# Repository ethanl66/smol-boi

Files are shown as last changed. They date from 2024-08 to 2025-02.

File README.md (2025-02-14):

# Smol boi

Custom 40% Keyboard PCB design files designed with KiCad 5.1.4. 
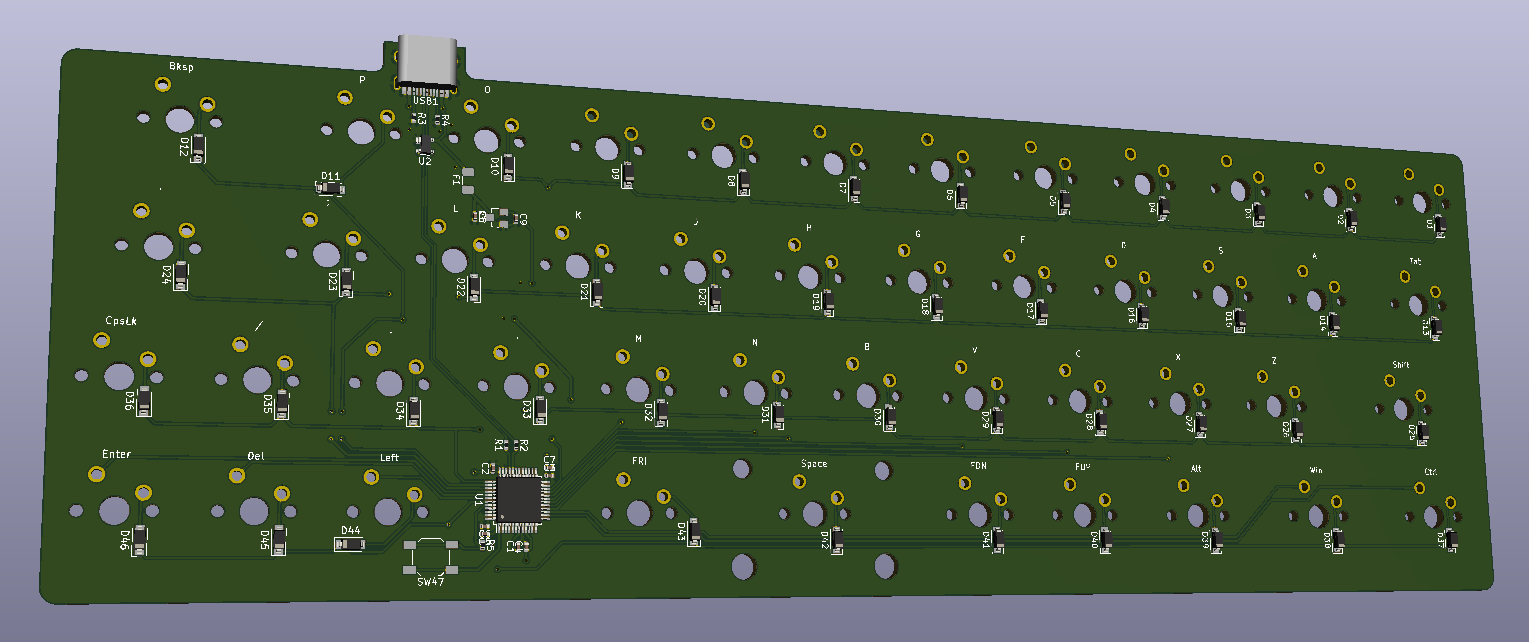
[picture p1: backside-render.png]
Backside Render of PCB Containing MCU and circuit elements Backside Render

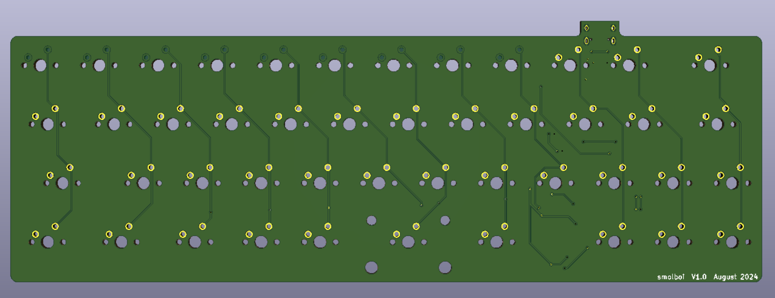
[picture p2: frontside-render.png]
Front Render of PCB Containing circuit elements Frontside Render


## Description

Smol Boi is a custom personal 40% keyboard PCB designed to provide a compact and efficient layout. This repository contains the KiCad design files including schematic and layout.
Firmware can be found at https://github.com/ethanl66/smolboi-firmware-v1.0

## Features

- 40% layout
- Custom layout with 46 keys
- USB-C connnectivity
- Flashable with DFU mode using USB-C
- Planned features for V2.0: LED indicators, hot-swap sockets, Bluetooth/2.4 GHz dongle, daughterboard, knob

## Contents

- `smolboi-pcb.sch`: Contains the PCB schematic
- `smolboi-pcb.kicad_pcb`: Contains the routing layout

## Acknowledgments

- Inspired by the community of keyboard enthusiasts
- Would not have been possible without r/MechanicalKeyboards

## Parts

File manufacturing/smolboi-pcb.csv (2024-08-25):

Comment | Designator | Footprint | LCSC
0.1uF | C1,C2,C3,C4,C5,C6 | Capacitor_SMD:C_0402_1005Metric | C307331
4.7uF | C7 | Capacitor_SMD:C_0402_1005Metric | C23733
1uF | C8,C9 | Capacitor_SMD:C_0402_1005Metric | C52923
D | D1,D2,D3,D4,D5,D6,D7,D8,D9,D10,D11,D12,D13,D14,D15,D16,D17,D18,D19,D20,D21,D22,D23,D24,D25,D26,D27,D28,D29,D30,D31,D32,D33,D34,D35,D36,D37,D38,D39,D40,D41,D42,D43,D44,D45,D46 | Diode_SMD:D_SOD-123 | C77978
500mA | F1 | Fuse:Fuse_1206_3216Metric | C70069
22 | R1,R2 | Resistor_SMD:R_0402_1005Metric | C6117666
5.1k | R3,R4 | Resistor_SMD:R_0402_1005Metric | C400635
10k | R5 | Resistor_SMD:R_0402_1005Metric | C850723
ESC | SW1 | MX_Only:MXOnly-1U-NoLED
O | SW10 | MX_Only:MXOnly-1U-NoLED
P | SW11 | MX_Only:MXOnly-1U-NoLED
Bksp | SW12 | MX_Only:MXOnly-1.75U-NoLED
Tab | SW13 | MX_Only:MXOnly-1.25U-NoLED
A | SW14 | MX_Only:MXOnly-1U-NoLED
S | SW15 | MX_Only:MXOnly-1U-NoLED
D | SW16 | MX_Only:MXOnly-1U-NoLED
F | SW17 | MX_Only:MXOnly-1U-NoLED
G | SW18 | MX_Only:MXOnly-1U-NoLED
H | SW19 | MX_Only:MXOnly-1U-NoLED
Q | SW2 | MX_Only:MXOnly-1U-NoLED
J | SW20 | MX_Only:MXOnly-1U-NoLED
K | SW21 | MX_Only:MXOnly-1U-NoLED
L | SW22 | MX_Only:MXOnly-1U-NoLED
; | SW23 | MX_Only:MXOnly-1U-NoLED
' | SW24 | MX_Only:MXOnly-1.5U-NoLED
Shift | SW25 | MX_Only:MXOnly-1.75U-NoLED
Z | SW26 | MX_Only:MXOnly-1U-NoLED
X | SW27 | MX_Only:MXOnly-1U-NoLED
C | SW28 | MX_Only:MXOnly-1U-NoLED
V | SW29 | MX_Only:MXOnly-1U-NoLED
W | SW3 | MX_Only:MXOnly-1U-NoLED
B | SW30 | MX_Only:MXOnly-1U-NoLED
N | SW31 | MX_Only:MXOnly-1U-NoLED
M | SW32 | MX_Only:MXOnly-1U-NoLED
, | SW33 | MX_Only:MXOnly-1U-NoLED
. | SW34 | MX_Only:MXOnly-1U-NoLED
/ | SW35 | MX_Only:MXOnly-1U-NoLED
CpsLk | SW36 | MX_Only:MXOnly-1U-NoLED
Ctrl | SW37 | MX_Only:MXOnly-1.25U-NoLED
Win | SW38 | MX_Only:MXOnly-1.25U-NoLED
Alt | SW39 | MX_Only:MXOnly-1.25U-NoLED
E | SW4 | MX_Only:MXOnly-1U-NoLED
FUP | SW40 | MX_Only:MXOnly-1U-NoLED
FDN | SW41 | MX_Only:MXOnly-1U-NoLED
Space | SW42 | MX_Only:MXOnly-2U-NoLED
FRI | SW43 | MX_Only:MXOnly-1U-NoLED
Left | SW44 | MX_Only:MXOnly-1U-NoLED
Del | SW45 | MX_Only:MXOnly-1U-NoLED
Enter | SW46 | MX_Only:MXOnly-1U-NoLED
SW_Push | SW47 | Button_Switch_SMD:SW_SPST_SKQG_WithStem | C115351
R | SW5 | MX_Only:MXOnly-1U-NoLED
T | SW6 | MX_Only:MXOnly-1U-NoLED
Y | SW7 | MX_Only:MXOnly-1U-NoLED
U | SW8 | MX_Only:MXOnly-1U-NoLED
I | SW9 | MX_Only:MXOnly-1U-NoLED
STM32F072CBTx | U1 | Package_QFP:LQFP-48_7x7mm_P0.5mm | C81720
PRTR5V0U2X | U2 | random-keyboard-parts:SOT143B | C12333
XC6206 | U3 | PMIC-LDO-XC6206P332MR-G_SOT23_:SOT-23 | C5446
HRO-TYPE-C-31-M-12 | USB1 | Type-C:HRO-TYPE-C-31-M-12-Assembly | C165948

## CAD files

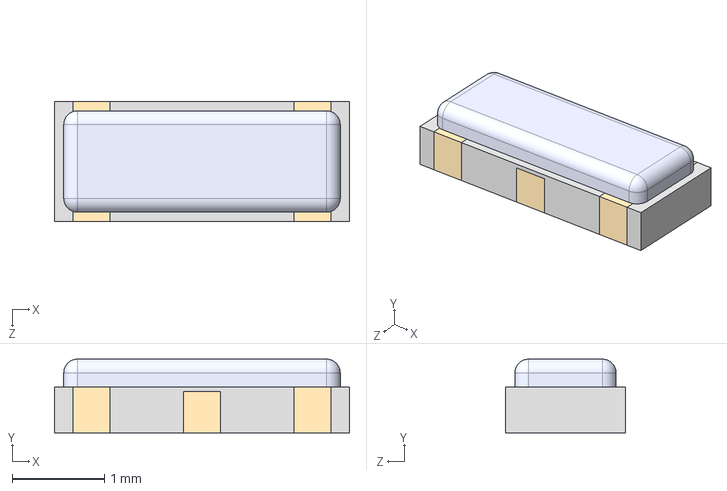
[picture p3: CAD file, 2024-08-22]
CSTNE8M00GH5C000R0/CSTNE8M00GH5C000R0.step
3.20 x 0.8 x 1.30 mm

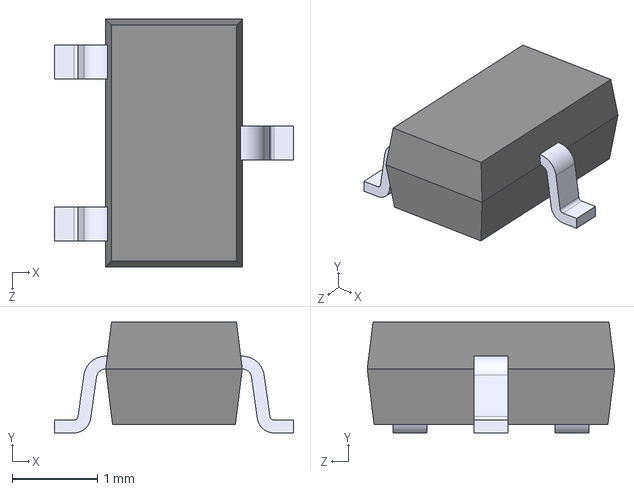
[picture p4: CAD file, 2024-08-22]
PMIC-LDO-XC6206P332MR-G_SOT23_/PMIC-LDO-XC6206P332MR-G_SOT23_.step
2.80 x 1.30 x 2.90 mm

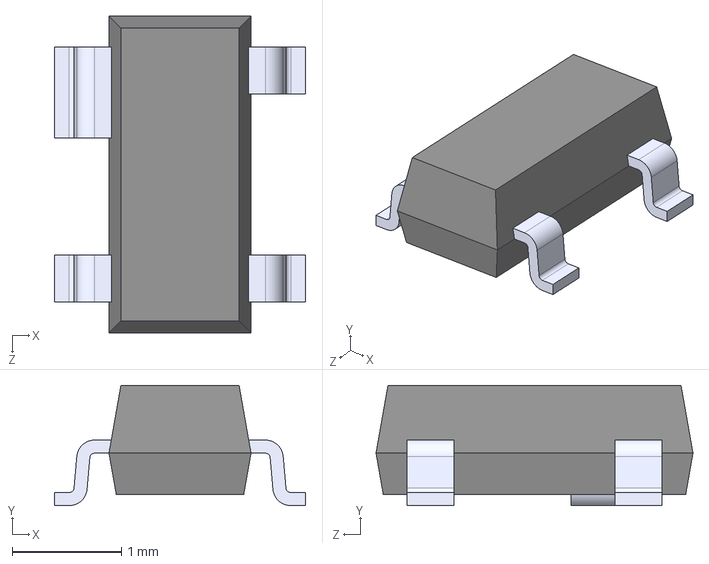
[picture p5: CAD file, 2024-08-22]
PRTR5V0U2X_215/PRTR5V0U2X_215.step
2.30 x 1.10 x 2.90 mm

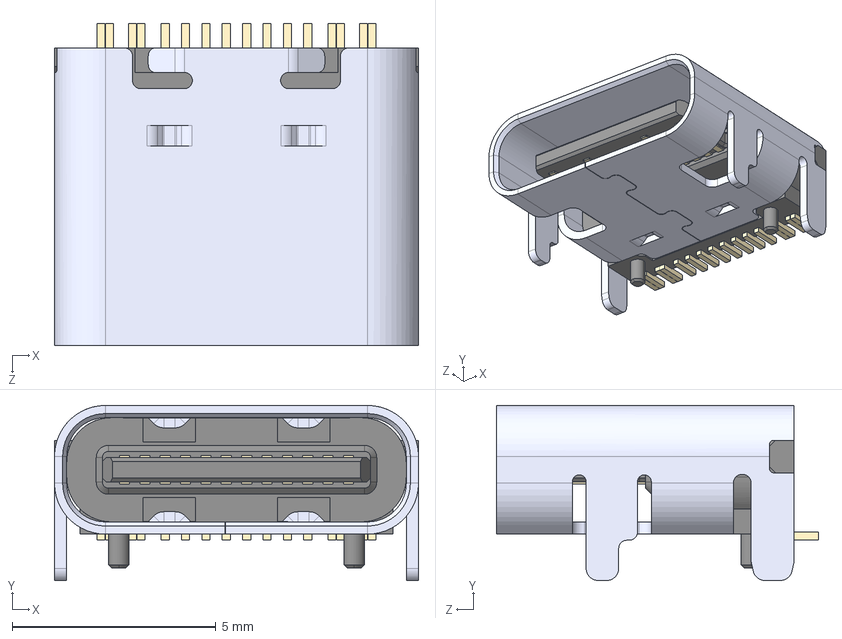
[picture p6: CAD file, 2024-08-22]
TYPE-C-31-M-12/TYPE-C-31-M-12.step
8.94 x 4.30 x 7.90 mm

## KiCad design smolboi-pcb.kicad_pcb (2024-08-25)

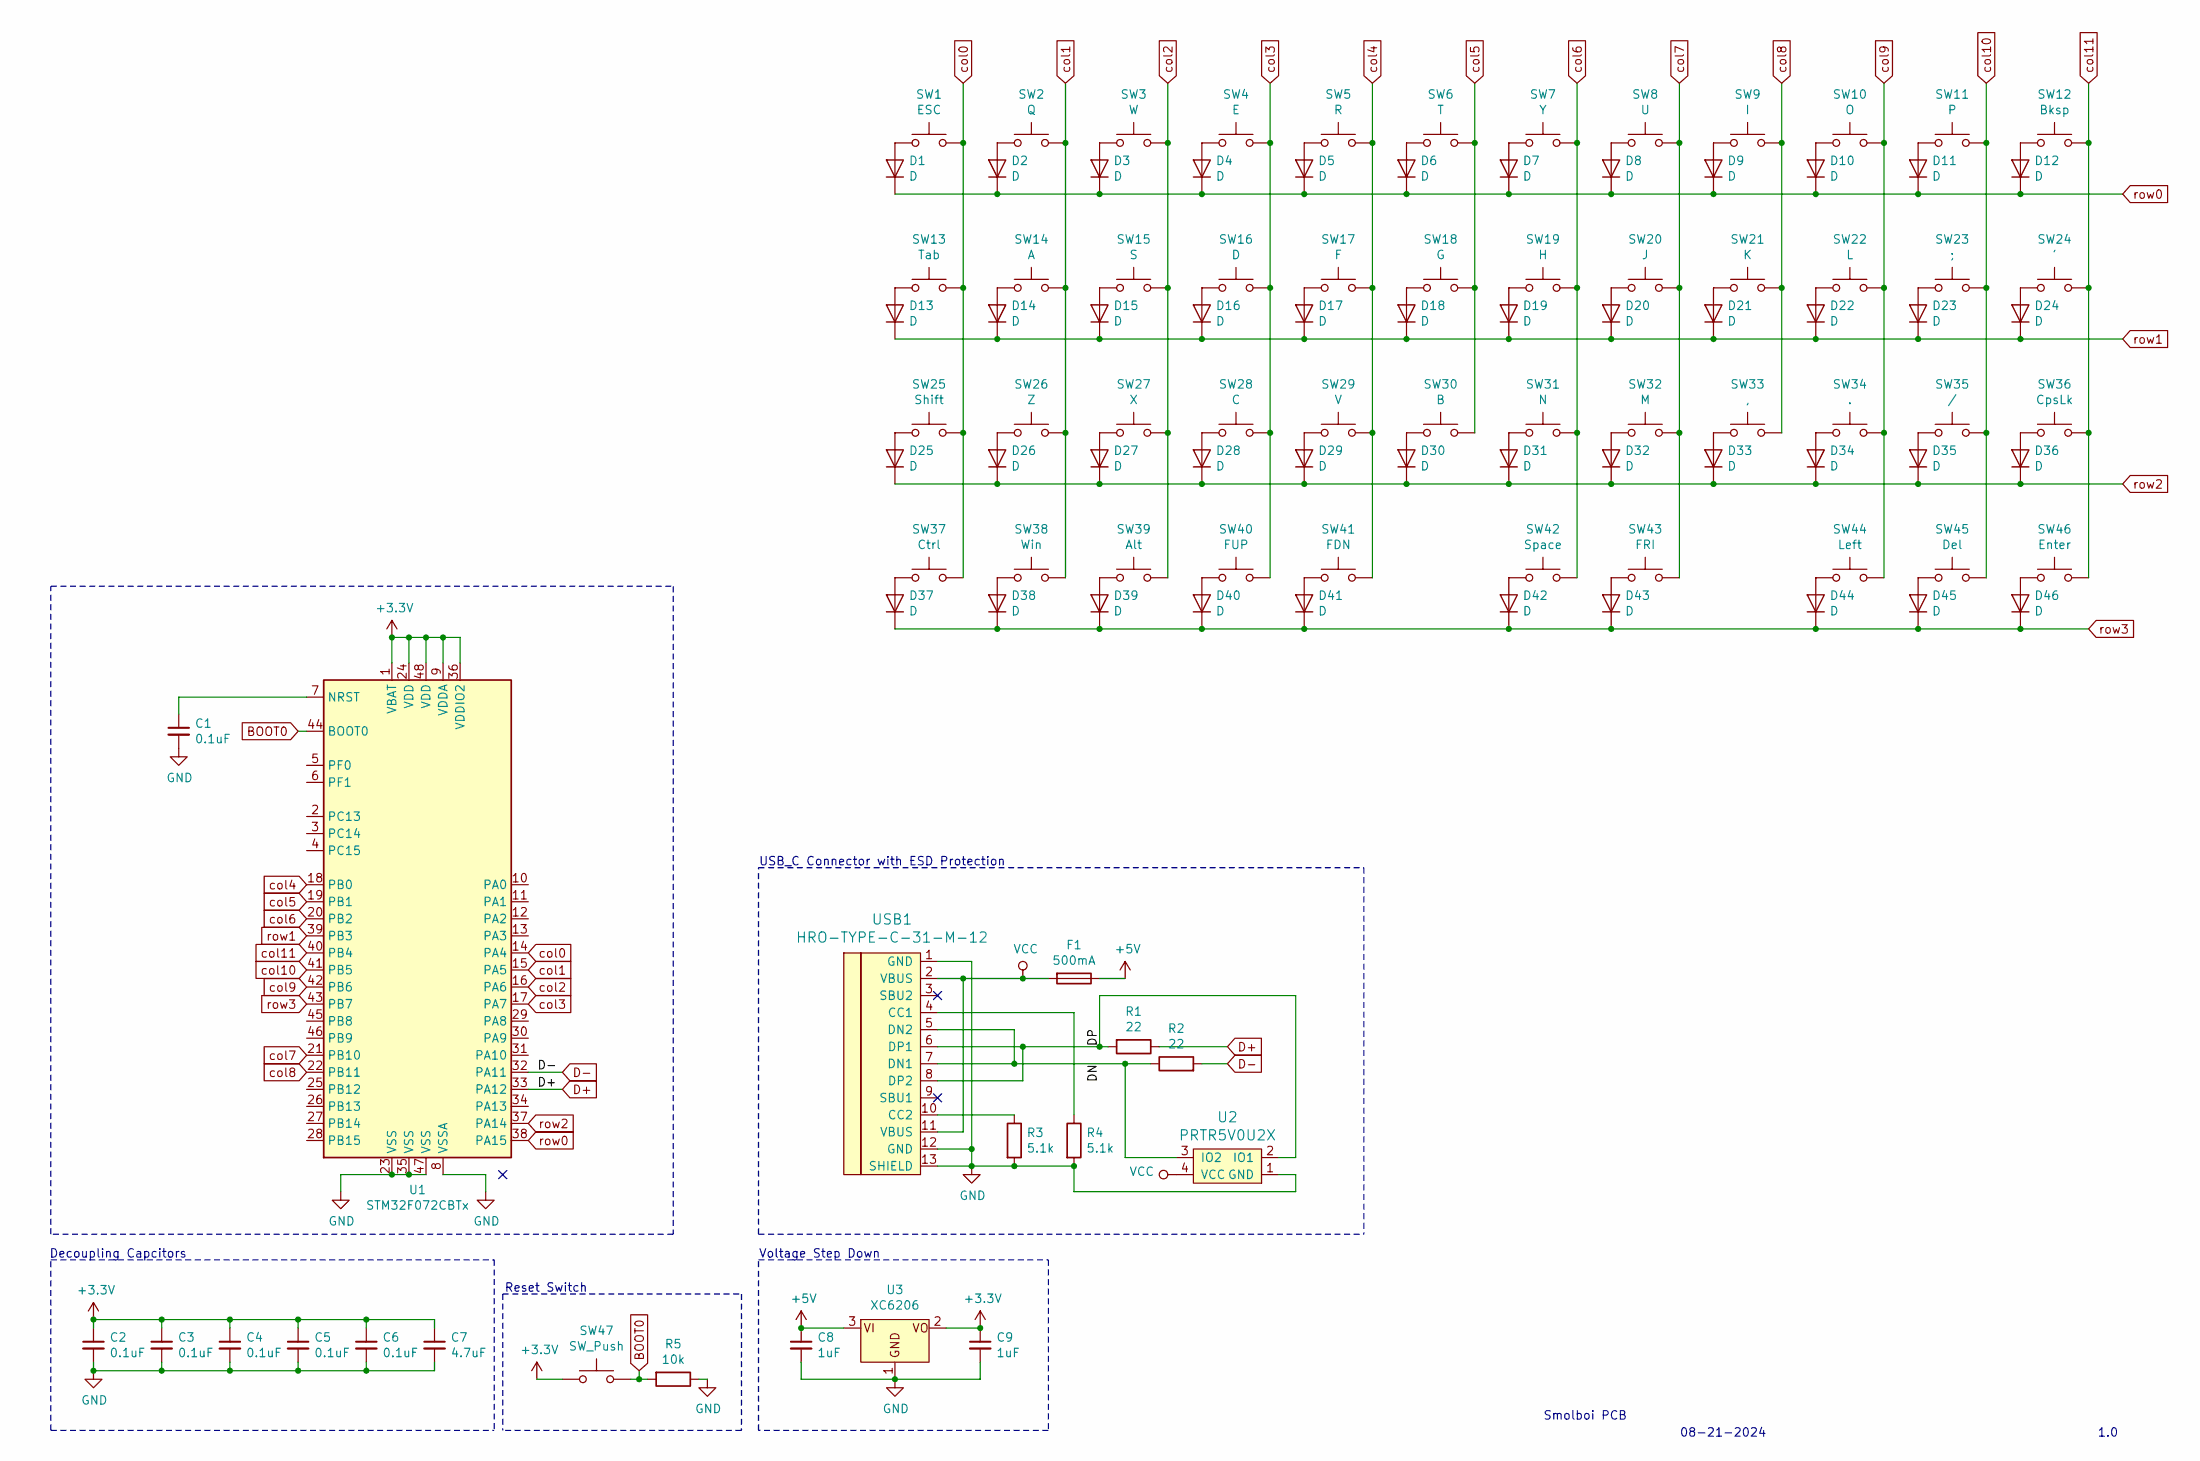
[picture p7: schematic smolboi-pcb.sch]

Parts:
C1, C2, C3, C4, C5, C6: 0.1uF; C_0402_1005Metric; LCSC C307331
C7: 4.7uF; C_0402_1005Metric; LCSC C23733
C8, C9: 1uF; C_0402_1005Metric; LCSC C52923
D1, D2, D3, D4, D5, D6, D7, D8, D9, D10, D11, D12, D13, D14, D15, D16, D17, D18, D19, D20, D21, D22, D23, D24, D25, D26, D27, D28, D29, D30, D31, D32, D33, D34, D35, D36, D37, D38, D39, D40, D41, D42, D43, D44, D45, D46: D; D_SOD-123; LCSC C77978
F1: 500mA; Fuse_1206_3216Metric; LCSC C70069
R1, R2: 22; R_0402_1005Metric; LCSC C6117666
R3, R4: 5.1k; R_0402_1005Metric; LCSC C400635
R5: 10k; R_0402_1005Metric; LCSC C850723
SW1: ESC; MXOnly-1U-NoLED
SW2: Q; MXOnly-1U-NoLED
SW3: W; MXOnly-1U-NoLED
SW4: E; MXOnly-1U-NoLED
SW5: R; MXOnly-1U-NoLED
SW6: T; MXOnly-1U-NoLED
SW7: Y; MXOnly-1U-NoLED
SW8: U; MXOnly-1U-NoLED
SW9: I; MXOnly-1U-NoLED
SW10: O; MXOnly-1U-NoLED
SW11: P; MXOnly-1U-NoLED
SW12: Bksp; MXOnly-1.75U-NoLED
SW13: Tab; MXOnly-1.25U-NoLED
SW14: A; MXOnly-1U-NoLED
SW15: S; MXOnly-1U-NoLED
SW16: D; MXOnly-1U-NoLED
SW17: F; MXOnly-1U-NoLED
SW18: G; MXOnly-1U-NoLED
SW19: H; MXOnly-1U-NoLED
SW20: J; MXOnly-1U-NoLED
SW21: K; MXOnly-1U-NoLED
SW22: L; MXOnly-1U-NoLED
SW23: ;; MXOnly-1U-NoLED
SW24: '; MXOnly-1.5U-NoLED
SW25: Shift; MXOnly-1.75U-NoLED
SW26: Z; MXOnly-1U-NoLED
SW27: X; MXOnly-1U-NoLED
SW28: C; MXOnly-1U-NoLED
SW29: V; MXOnly-1U-NoLED
SW30: B; MXOnly-1U-NoLED
SW31: N; MXOnly-1U-NoLED
SW32: M; MXOnly-1U-NoLED
SW33: ,; MXOnly-1U-NoLED
SW34: .; MXOnly-1U-NoLED
SW35: /; MXOnly-1U-NoLED
SW36: CpsLk; MXOnly-1U-NoLED
SW37: Ctrl; MXOnly-1.25U-NoLED
SW38: Win; MXOnly-1.25U-NoLED
SW39: Alt; MXOnly-1.25U-NoLED
SW40: FUP; MXOnly-1U-NoLED
SW41: FDN; MXOnly-1U-NoLED
SW42: Space; MXOnly-2U-NoLED
SW43: FRI; MXOnly-1U-NoLED
SW44: Left; MXOnly-1U-NoLED
SW45: Del; MXOnly-1U-NoLED
SW46: Enter; MXOnly-1U-NoLED
SW47: SW_Push; SW_SPST_SKQG_WithStem; LCSC C115351
U1: STM32F072CBTx; LQFP-48_7x7mm_P0.5mm; LCSC C81720
U2: PRTR5V0U2X; SOT143B; LCSC C12333
U3: XC6206; SOT-23; LCSC C5446
USB1: HRO-TYPE-C-31-M-12; HRO-TYPE-C-31-M-12-Assembly; LCSC C165948

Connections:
+3V3: C2.1, C3.1, C4.1, C5.1, C6.1, C7.1, C9.1, SW47.1, U1.1 (VBAT), U1.9 (VDDA), U1.24 (VDD), U1.36 (VDDIO2), U1.48 (VDD), U3.2
+5V: C8.1, F1.1, U3.3
/DN: R2.1, U2.3 (IO2), USB1.5 (DN2), USB1.7 (DN1)
/DP: R1.2, U2.2 (IO1), USB1.6 (DP1), USB1.8 (DP2)
BOOT0: R5.2, SW47.2, U1.44 (BOOT0)
D+: R1.1, U1.33 (PA12)
D-: R2.2, U1.32 (PA11)
GND: C1.2, C2.2, C3.2, C4.2, C5.2, C6.2, C7.2, C8.2, C9.2, R3.2, R4.2, R5.1, U1.8 (VSSA), U1.23 (VSS), U1.35 (VSS), U1.47 (VSS), U2.1 (GND), U3.1, USB1.1 (GND), USB1.12 (GND), USB1.13 (SHIELD)
unnamed: C1.1, U1.7 (NRST)
unnamed: D1.2 (A), SW1.1
unnamed: D2.2 (A), SW2.1
unnamed: D3.2 (A), SW3.1
unnamed: D4.2 (A), SW4.1
unnamed: D5.2 (A), SW5.1
unnamed: D6.2 (A), SW6.1
unnamed: D7.2 (A), SW7.1
unnamed: D8.2 (A), SW8.1
unnamed: D9.2 (A), SW9.1
unnamed: D10.2 (A), SW10.1
unnamed: D11.2 (A), SW11.1
unnamed: D12.2 (A), SW12.1
unnamed: D13.2 (A), SW13.1
unnamed: D14.2 (A), SW14.1
unnamed: D15.2 (A), SW15.1
unnamed: D16.2 (A), SW16.1
unnamed: D17.2 (A), SW17.1
unnamed: D18.2 (A), SW18.1
unnamed: D19.2 (A), SW19.1
unnamed: D20.2 (A), SW20.1
unnamed: D21.2 (A), SW21.1
unnamed: D22.2 (A), SW22.1
unnamed: D23.2 (A), SW23.1
unnamed: D24.2 (A), SW24.1
unnamed: D25.2 (A), SW25.1
unnamed: D26.2 (A), SW26.1
unnamed: D27.2 (A), SW27.1
unnamed: D28.2 (A), SW28.1
unnamed: D29.2 (A), SW29.1
unnamed: D30.2 (A), SW30.1
unnamed: D31.2 (A), SW31.1
unnamed: D32.2 (A), SW32.1
unnamed: D33.2 (A), SW33.1
unnamed: D34.2 (A), SW34.1
unnamed: D35.2 (A), SW35.1
unnamed: D36.2 (A), SW36.1
unnamed: D37.2 (A), SW37.1
unnamed: D38.2 (A), SW38.1
unnamed: D39.2 (A), SW39.1
unnamed: D40.2 (A), SW40.1
unnamed: D41.2 (A), SW41.1
unnamed: D42.2 (A), SW42.1
unnamed: D43.2 (A), SW43.1
unnamed: D44.2 (A), SW44.1
unnamed: D45.2 (A), SW45.1
unnamed: D46.2 (A), SW46.1
unnamed: R3.1, USB1.10 (CC2)
unnamed: R4.1, USB1.4 (CC1)
VCC: F1.2, U2.4 (VCC), USB1.2 (VBUS), USB1.11 (VBUS)
col0: SW1.2, SW13.2, SW25.2, SW37.2, U1.14 (PA4)
col1: SW2.2, SW14.2, SW26.2, SW38.2, U1.15 (PA5)
col2: SW3.2, SW15.2, SW27.2, SW39.2, U1.16 (PA6)
col3: SW4.2, SW16.2, SW28.2, SW40.2, U1.17 (PA7)
col4: SW5.2, SW17.2, SW29.2, SW41.2, U1.18 (PB0)
col5: SW6.2, SW18.2, SW30.2, U1.19 (PB1)
col6: SW7.2, SW19.2, SW31.2, SW42.2, U1.20 (PB2)
col7: SW8.2, SW20.2, SW32.2, SW43.2, U1.21 (PB10)
col8: SW9.2, SW21.2, SW33.2, U1.22 (PB11)
col9: SW10.2, SW22.2, SW34.2, SW44.2, U1.42 (PB6)
col10: SW11.2, SW23.2, SW35.2, SW45.2, U1.41 (PB5)
col11: SW12.2, SW24.2, SW36.2, SW46.2, U1.40 (PB4)
row0: D1.1 (K), D2.1 (K), D3.1 (K), D4.1 (K), D5.1 (K), D6.1 (K), D7.1 (K), D8.1 (K), D9.1 (K), D10.1 (K), D11.1 (K), D12.1 (K), U1.38 (PA15)
row1: D13.1 (K), D14.1 (K), D15.1 (K), D16.1 (K), D17.1 (K), D18.1 (K), D19.1 (K), D20.1 (K), D21.1 (K), D22.1 (K), D23.1 (K), D24.1 (K), U1.39 (PB3)
row2: D25.1 (K), D26.1 (K), D27.1 (K), D28.1 (K), D29.1 (K), D30.1 (K), D31.1 (K), D32.1 (K), D33.1 (K), D34.1 (K), D35.1 (K), D36.1 (K), U1.37 (PA14)
row3: D37.1 (K), D38.1 (K), D39.1 (K), D40.1 (K), D41.1 (K), D42.1 (K), D43.1 (K), D44.1 (K), D45.1 (K), D46.1 (K), U1.43 (PB7)

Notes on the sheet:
Smolboi PCB
08-21-2024
1.0
USB_C Connector with ESD Protection
Voltage Step Down
Decoupling Capcitors
Reset Switch

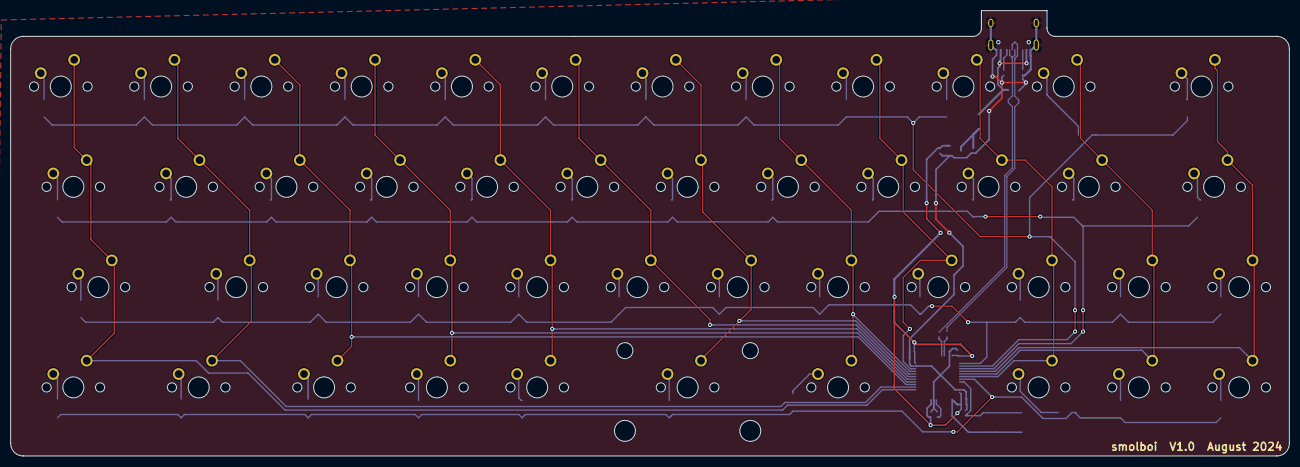
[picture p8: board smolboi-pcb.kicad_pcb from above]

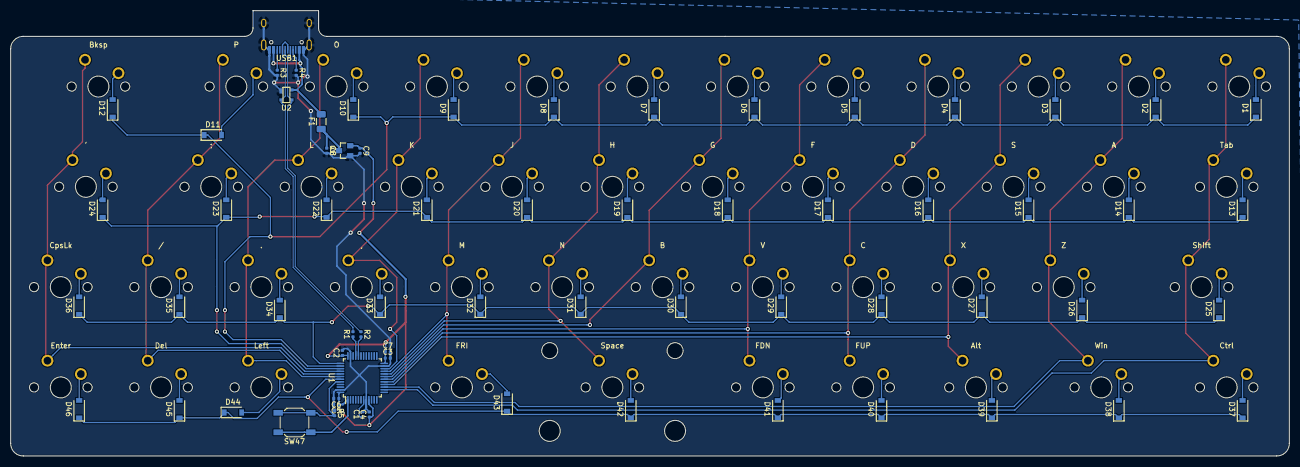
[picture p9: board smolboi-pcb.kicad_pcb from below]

Board: 2 copper layers, 242.9 x 84.6 mm, 112 parts (66 on the bottom side), 74 nets.

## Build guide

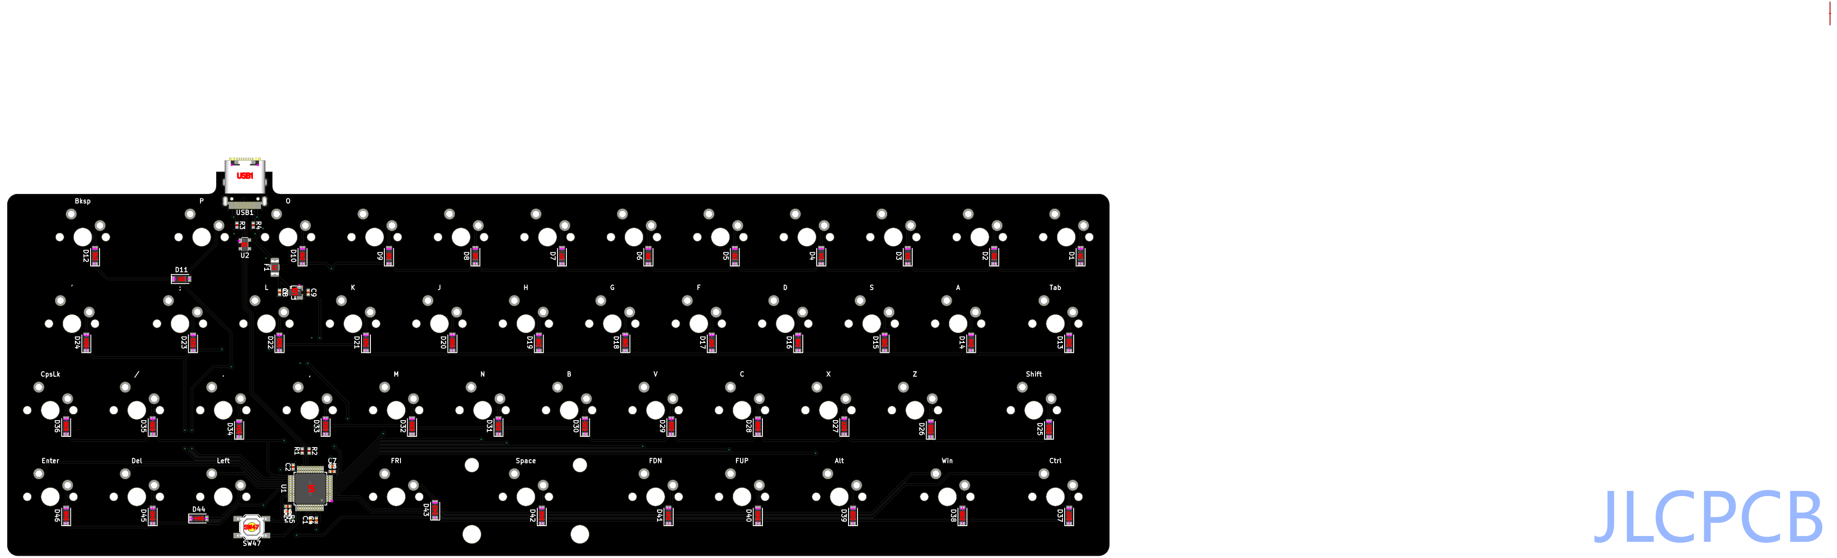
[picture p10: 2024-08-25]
manufacturing/JLCPCB_placements.png

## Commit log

2024-07-20 add 3 submodules
    [smolboi-pcb.kicad_pcb, smolboi-pcb.sch]
2024-07-21 add 3 libraries to kicad
2024-07-21 schematic work, add scottokeebs submodule
2024-07-21 schematic before check
    [smolboi-pcb.sch]
2024-07-23 ceramic oscillator, major schematic modules finalized
    [smolboi-pcb.sch]
2024-08-22 up to finish diff pair routing
    [CSTNE8M00GH5C000R0.step, PMIC-LDO-XC6206P332MR-G_SOT23_.step, PMIC-XC6206P182MR_SOT23_.step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]
2024-08-24 staggered layout, routed diff pair on right side
    [smolboi-pcb.kicad_pcb, smolboi-pcb.sch]
2024-08-25 gnd fill around oscillator, all pwr routed, NRST vias
    [smolboi-pcb.kicad_pcb]
2024-08-25 routed matrix
    [smolboi-pcb.kicad_pcb, smolboi-pcb.sch]
2024-08-25 inc USB C solder pad margin
    [smolboi-pcb.kicad_pcb]
2024-08-25 replaced with STM32F072CBT6, rerouted
    [smolboi-pcb.kicad_pcb, smolboi-pcb.sch]
2024-08-25 ground fills
    [smolboi-pcb.kicad_pcb]
2024-08-25 DRC, final aesthetic touches
    [smolboi-pcb.kicad_pcb]
2024-08-25 gerbers and drill in zip
    [smolboi-pcb-B_Cu.gbr, smolboi-pcb-B_Mask.gbr, smolboi-pcb-B_SilkS.gbr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]
2024-08-25 jlcpcb bom and pos files
    [smolboi-pcb.csv, smolboi-pcb.kicad_pcb, smolboi-pcb.sch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]
